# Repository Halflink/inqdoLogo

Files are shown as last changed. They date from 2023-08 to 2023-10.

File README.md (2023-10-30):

# INQDO LOGO
---
## PROJECT
| Project name: | Halflink/inqdoLogo |
|---|---|
| Author: | Jeroen van Zwam |
| Date: | 2023-07-02 |  
| Last update: | 2023-10-10 |
| Project type: | Raspberry Pico | 
---
## EXECUTABLES
* Start main.py

## PROJECT DESCRIPTION
I came up with the idea for this project when the company I work for asked the
employees if they had suggestions to put in an steampunk themed display cabinet.
I already had a strip of neopixels that I wanted to experiment with, all I
needed was an idea -> a frame with the company logo for in the display cabinet.
The frame is a 3D printed representation of copper piping. As the frame is too
big to print in one go I designed it in several parts using an peg/hole assembly.
At the connections I made flanges with a bolt detail to mimic more copper piping.
The canvas used is a piece of triplex in which I have laser-cutted the logo.
The charring of the triplex gives a more rusty, steampunky look, so I decided
not to varnish the triplex. Behind the triplex a semi-transparent white pane
covers the neopixels.
As the inQdo logo is quite intricate I needed a way to clamp and structure the
neopixel strip. To do that I measured up one single pixel and created a bracket
for it. this bracket is used as a template to create a bracket per letter, which
is basically a concatenation of multiple single pixel brackets.
The housing for the batteries and the pico are intended to be metallic (tin) so
they are part of the steampunk look.
---
## WORKINGS
### turning on off
To turn the logo on, flip the switch in the ON position.<br>
You could also power over the micro usb connector of the pico. 

### patterns
I created 3 different patterns, which run one after the other. 

---
## PARTS LIST
* [raspberry Pico](https://elektronicavoorjou.nl/product/raspberry-pi-pico/)
* [Tumble switch](https://www.benselectronics.nl/mini-tuimel-schakelaar.html)
* [Battery holder](https://www.kiwi-electronics.com/nl/3x-aaa-batterijhouder-met-jst-connector-3734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)
* [NeoPixel strip](https://www.bitsandparts.nl/LED-Strip-RGB-WS2812-5V-IP67-60-LEDs-m-5-meter-zwart-p1892774)

---
## PROJECT PROGRESS

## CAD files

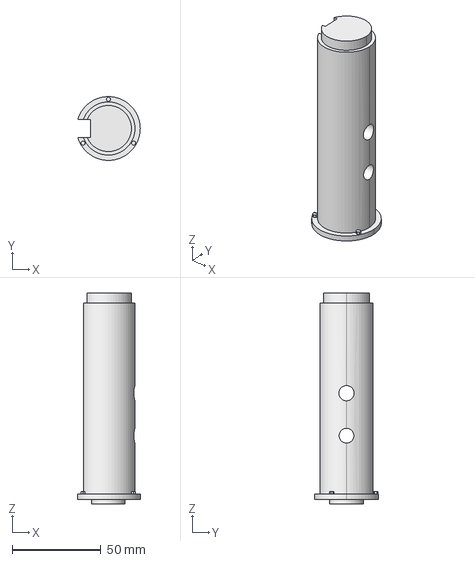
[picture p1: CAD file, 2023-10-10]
FreeCad/frameTubeType5.FCStd
35.3 x 36.0 x 119.0 mm

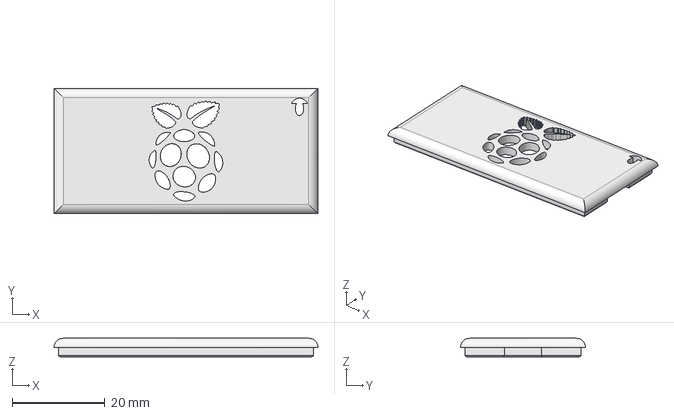
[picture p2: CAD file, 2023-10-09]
FreeCad/picoBracketLid.FCStd
57.0 x 27.0 x 4.00 mm

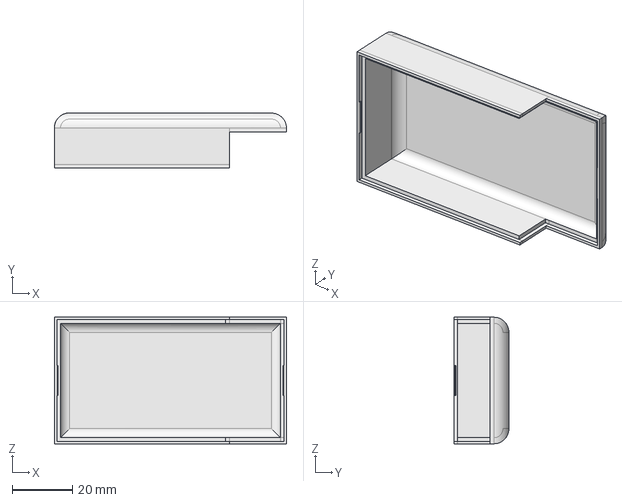
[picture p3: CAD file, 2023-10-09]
FreeCad/batteryHolderCap.FCStd
77.0 x 18.2 x 42.0 mm

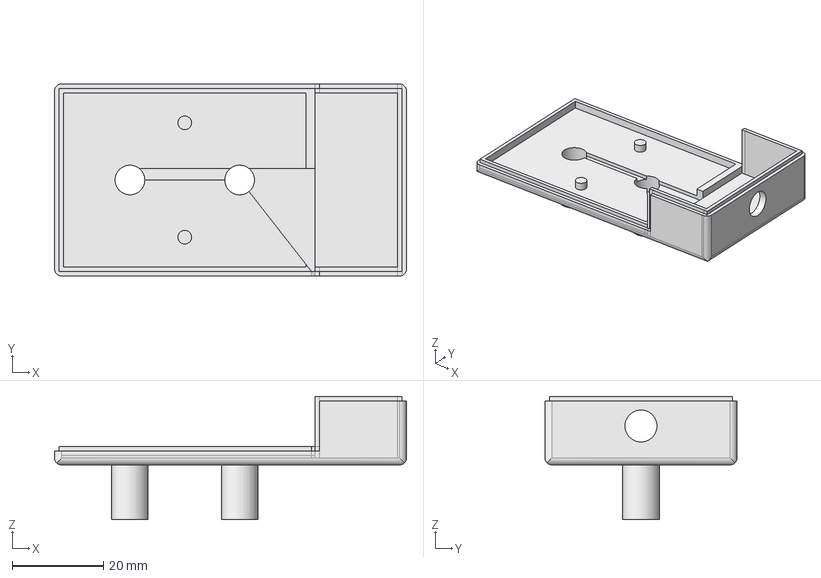
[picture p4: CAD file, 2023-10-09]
FreeCad/batteryHolder.FCStd
77.0 x 42.0 x 27.0 mm

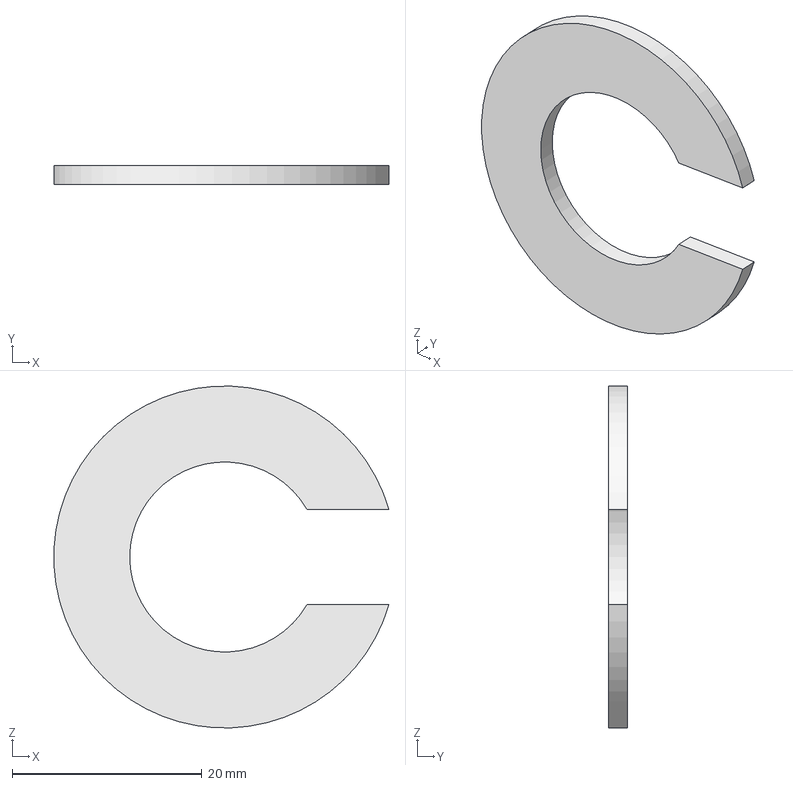
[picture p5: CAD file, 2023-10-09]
FreeCad/flam.FCStd
35.3 x 2.00 x 36.0 mm

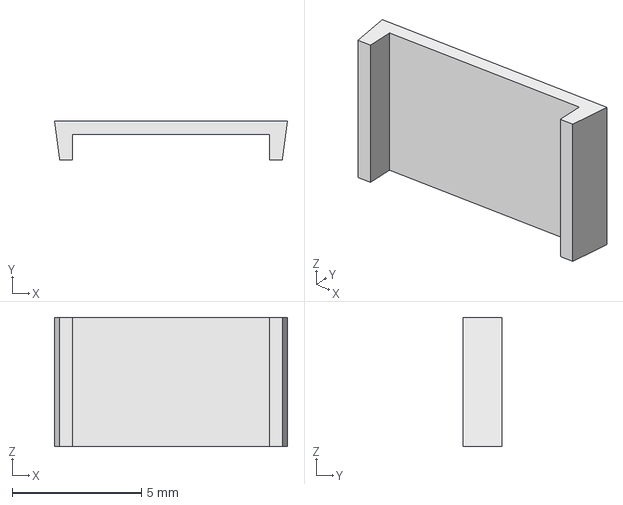
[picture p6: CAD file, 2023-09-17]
FreeCad/wireCram.FCStd
9.00 x 1.50 x 5.00 mm

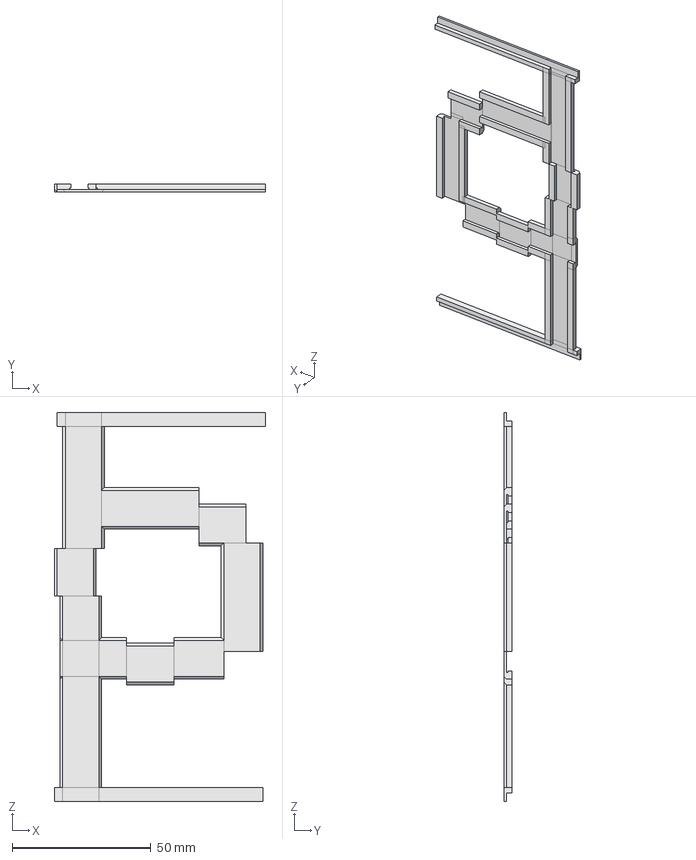
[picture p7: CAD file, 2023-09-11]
FreeCad/neopixelbracket_O.FCStd
76.0 x 3.00 x 140.0 mm

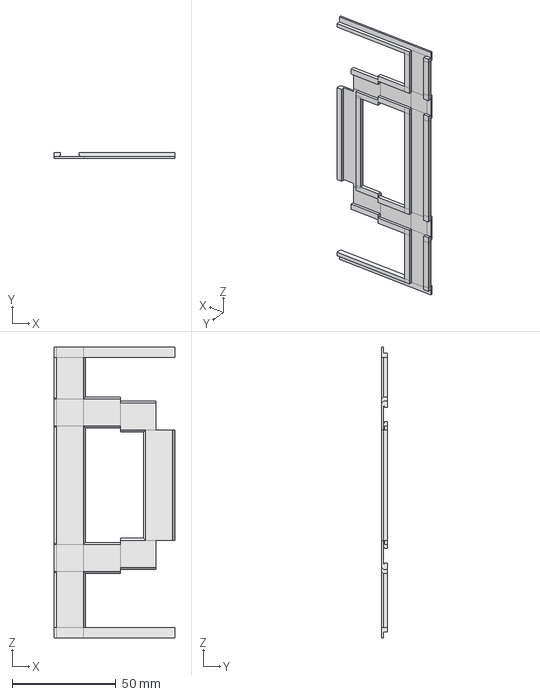
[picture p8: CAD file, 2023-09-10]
FreeCad/neopixelbracket_D.FCStd
58.0 x 3.00 x 140.0 mm

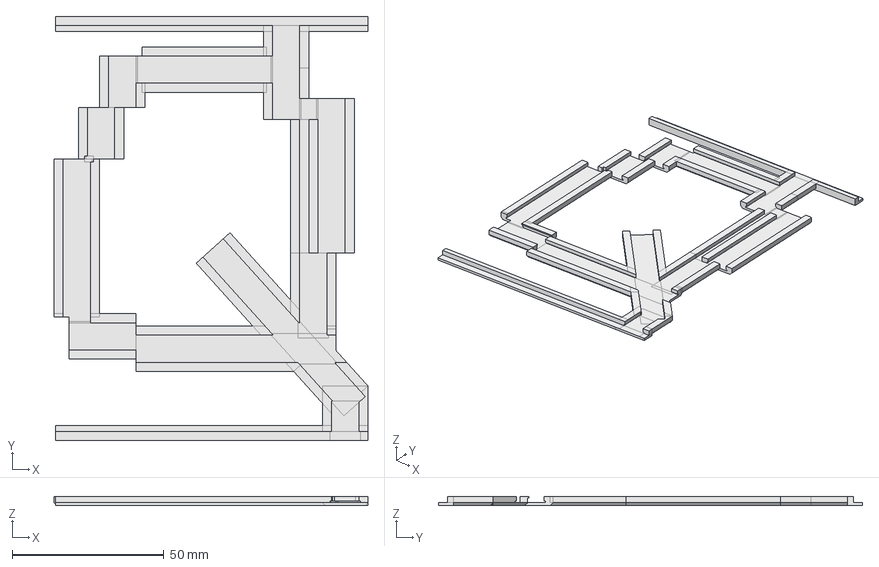
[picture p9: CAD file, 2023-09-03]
FreeCad/neopixelbracket_Q.FCStd
103.5 x 139.8 x 3.00 mm

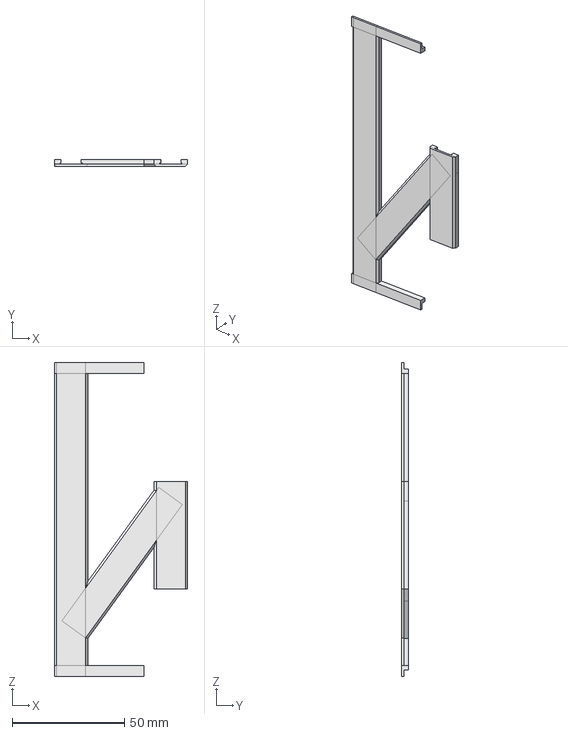
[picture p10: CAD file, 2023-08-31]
FreeCad/neopixelbracket_N.FCStd
59.5 x 3.00 x 140.0 mm

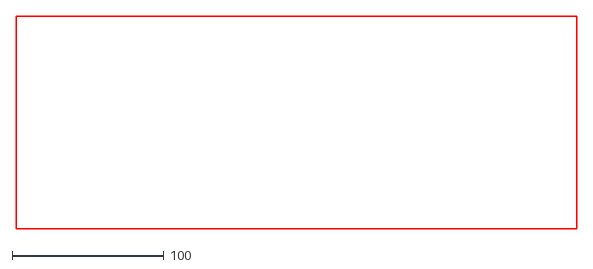
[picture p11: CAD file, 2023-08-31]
FreeCad/backplate.dxf
370.0 x 140.0

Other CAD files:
FreeCad/batteryCap.FCStd
FreeCad/picoBracketLid-Body.stl
FreeCad/batteryHolderCap-Body.stl
FreeCad/batteryHolder-Body.stl
FreeCad/wireCram-BodySketch.stl
FreeCad/neopixelbracket_O-Body.stl
FreeCad/neopixelbracket_D-Body.stl
FreeCad/frameCorner.FCStd
FreeCad/frameMof.FCStd
FreeCad/frameMofType2.FCStd
FreeCad/frameTubeType1.FCStd
FreeCad/frameTubeType2.FCStd
FreeCad/frameTubeType3.FCStd
FreeCad/frameTubeType4.FCStd
FreeCad/inqdo.FCStd
FreeCad/inqdoLogo.FCStd
FreeCad/neopixelbracket.FCStd
FreeCad/neopixelbracket_I.FCStd
FreeCad/picoBracket.FCStd
FreeCad/picoBracket_v2.FCStd

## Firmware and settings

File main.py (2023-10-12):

import time
from JsonHandler import JsonHandler
from neopixel import Neopixel
from machine import Pin
from pixelCharacters import PixelCharacters


class Main:

    def __init__(self):
        self.settings = JsonHandler()
        self.pixels = Neopixel(self.settings.numberOfPixels, self.settings.state, self.settings.neoPixelPin,
                               self.settings.mode)
        self.pixels.brightness(self.settings.brightness)
        self.pixels.fill(self.settings.white)
        self.led = Pin(self.settings.ledPin, Pin.OUT)
        self.led.toggle()
        self.pixelCharacters = PixelCharacters(self.pixels, self.settings.characterSettings, self.settings.white)

    def show(self, sleep):
        self.pixels.show()
        time.sleep(sleep)

    def pattern_1(self):
        for i in range(3):
            for colour in [self.settings.yellow, self.settings.orange, self.settings.blue]:
                self.pixels.fill(self.settings.white)
                self.show(1)
                self.pixelCharacters.set_character_colour('I', colour)
                self.pixelCharacters.set_character_colour('O', colour)
                self.show(0.5)
                self.pixels.fill(self.settings.white)
                self.pixelCharacters.set_character_colour('N', colour)
                self.pixelCharacters.set_character_colour('D', colour)
                self.show(0.5)
                self.pixels.fill(self.settings.white)
                self.pixelCharacters.set_character_colour('Q', colour)
                self.show(3)

    def pattern_2(self):
        for colour in [self.settings.blue, self.settings.orange, self.settings.yellow]:
            self.pixels.fill(self.settings.white)
            self.show(1)
            self.pixelCharacters.circle_character('Q', colour, colour)
            self.show(3)

    def pattern_3(self):
        for colour in [self.settings.blue, self.settings.orange, self.settings.yellow]:
            self.pixels.fill(self.settings.white)
            self.show(1)
            self.pixelCharacters.circle_character('I', colour, self.settings.white)
            self.show(0.5)
            self.pixelCharacters.circle_character('N', colour, self.settings.white)
            self.show(0.5)
            self.pixelCharacters.circle_character('Q', colour, self.settings.white)
            self.show(0.5)
            self.pixelCharacters.circle_character('D', colour, self.settings.white)
            self.show(0.5)
            self.pixelCharacters.circle_character('O', colour, self.settings.white)
            self.show(3)


if __name__ == '__main__':
    print('start')
    main = Main()

    while True:
        main.pattern_3()
        main.pattern_2()
        main.pattern_1()

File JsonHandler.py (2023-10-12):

import json as json


class JsonHandler:

    def __init__(self):
        with open("init.json") as jsonFile:
            init_info = json.load(jsonFile)
            jsonFile.close()

            # set colours
            colours = init_info['colours']
            self.white = self.get_rgb(colours['white'])
            self.yellow = self.get_rgb(colours['yellow'])
            self.orange = self.get_rgb(colours['orange'])
            self.blue = self.get_rgb(colours['blue'])
            self.green = self.get_rgb(colours['green'])
            self.red = self.get_rgb(colours['red'])

            # set character pixels
            self.characterSettings = []
            self.add_character_settings(init_info['characters'])

            # set neopixel
            neoPixelSettings = init_info['neoPixelSettings']
            self.numberOfPixels = neoPixelSettings['numberOfPixels']
            self.state = neoPixelSettings['state']
            self.neoPixelPin = neoPixelSettings['pin']
            self.mode = neoPixelSettings['mode']
            self.brightness = neoPixelSettings['pixelBrightness']

            # set LED pin
            self.ledPin = init_info['ledPin']

    @staticmethod
    def get_rgb(colour):
        rgb = (colour[0], colour[1], colour[2])
        return rgb

    def add_character_settings(self, characters):
        for character in characters:
            characterSetting = [character, characters[character]]
            self.characterSettings.append(characterSetting)

    def print_settings(self):
        print("white: {}, yellow: {}, blue: {}, orange: {}, green: {}".format(self.white, self.yellow, self.blue,
                                                                              self.orange, self.green))
        print(self.characterSettings)


if __name__ == '__main__':
    jsonHandler = JsonHandler()
    jsonHandler.print_settings()

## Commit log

2023-06-25 Added Freecad designs
    inQdo logo, corner of frame
    [frameCorner.FCStd, inqdo.FCStd, inqdo_poging_1.FCStd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]
2023-06-29 added pipe
    added pipe
    [TopTubeType1.FCStd, frameCorner.FCStd]
2023-06-29 Finished PiptType1
    FinishedPipeType1
    [TopTubeType1.FCStd]
2023-06-30 Added mof design
    Added mof design
    [TopTubeType1.FCStd, frameMof.FCStd, framePipeType2.FCStd]
2023-06-30 Added side pipe designs
    Added side pipe designs
    [frameCorner.FCStd, framePipeLeft.FCStd]
2023-07-01 Renamed to correct names
    [frameTubeType1.FCStd, frameTubeType2.FCStd, frameTubeType3.FCStd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]
2023-07-01 Added bracket for pico
    Added bracket for pico
    Also chanfged tube type 2: added flans
    [frameMof.FCStd, frameTubeType3.FCStd, picoBracket.FCStd]
2023-07-02 added pickBracket2
    [frameMof.FCStd, inqdoLogo.FCStd, picoBracket.FCStd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]
2023-07-02 Update picoBracket_v2.FCStd
    Finished pi bracket
    [picoBracket_v2.FCStd]
2023-07-02 Added mof type 2: stand function
    Added mof type 2: stand function
    [frameMofType2.FCStd]
2023-07-02 Added new type of tube, to house pi bracket
    Added new type of tube, to house pi bracket
    [frameTubeType4.FCStd]
2023-07-04 added lid
    Added piBracket lid, changed type 2 (2 cm shorter)
    [frameTubeType2.FCStd, picoBracketLid.FCStd, picoBracket_v2.FCStd]
2023-07-16 Finished lid for PI bracket
    first iteration
    [picoBracketLid.FCStd]
2023-07-18 Changed lid size
    Changed lid size
    [picoBracketLid.FCStd]
2023-07-19 tinkering lid
    tinkering lid
    [picoBracketLid.FCStd]
2023-08-03 add neopixel bracket
    add neopixel bracket
    [batteryHolder.FCStd, neopixelbracket.FCStd, picoBracket_v2.FCStd]
2023-08-06 Added neopixelholder for "N"
    Added neopixelholder for "N"
    [neopixelbracket_I.FCStd]
2023-08-24 Create bracket for N
    Create bracket for N
    [neopixelbracket_I.FCStd, neopixelbracket_N.FCStd]
2023-08-24 Added testrun neopixels
    [backplate.dxf, picoBracketLid.FCStd]
2023-09-02 added neopixel bracked Q
    added neopixel bracked Q, first test
    [neopixelbracket_Q.FCStd]
2023-09-03 Update neopixelbracket_Q.FCStd
    Finished set up
    [neopixelbracket_Q.FCStd]
2023-09-10 Added neopixelbracket D
    [neopixelbracket_D-Body.stl, neopixelbracket_D.FCStd]
2023-09-10 Update neopixelbracket D
    [neopixelbracket_D-Body.stl, neopixelbracket_D.FCStd]
2023-09-11 Added neopixelbody-O
    [neopixelbracket_O-Body.stl, neopixelbracket_O.FCStd]
2023-09-17 added wireCram
    [wireCram-BodySketch.stl, wireCram.FCStd]
2023-09-17 changed code: added all characters
    [batteryHolder.FCStd, wireCram-BodySketch.stl, wireCram.FCStd]
2023-09-17 added pipe type 5
    [frameTubeType5.FCStd]
2023-09-18 changed battery holder.
    [batteryHolder.FCStd]
2023-09-18 Solved batteryholder issues
    [batteryHolder-Body.stl, batteryHolder.FCStd]
2023-10-07 Added test batteryHolderCap
    [batteryHolderCap-Body.stl, batteryHolderCap.FCStd]
2023-10-09 Added battery cap and altered lid
    [batteryHolderCap.FCStd, flam.FCStd, picoBracketLid.FCStd]
2023-10-09 altered cap
    [batteryHolderCap.FCStd]
2023-10-09 updated pico lid
    [picoBracketLid-Body.stl, picoBracketLid.FCStd]
